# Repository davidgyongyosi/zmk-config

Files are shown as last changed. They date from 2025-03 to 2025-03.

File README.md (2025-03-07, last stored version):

<picture align="center">
  <source media="(prefers-color-scheme: dark)" srcset="/docs/images/TOTEM_logo_dark.svg">
  <source media="(prefers-color-scheme: light)" srcset="/docs/images/TOTEM_logo_bright.svg">
  TOTEM logo
</picture>

<h1 align="center">T O T E M</h1>

TOTEM is a 38 key column-staggered choc split keyboard. It is meant to be used with a [Seeed Studio XIAO nRF52840 BLE](https://www.seeedstudio.com/Seeed-XIAO-BLE-nRF52840-p-5201.html) or [XIAO RP2040](https://www.seeedstudio.com/XIAO-RP2040-v1-0-p-5026.html).
It was created for the SEEED XIAO keyboard contest.\
[Here](https://www.hackster.io/geist/totem-a-tiny-splitkeyboard-with-splay-cb2e43) you can read about the process of making it.

***

## LAYOUT

TOTEM layout

***

## PCB

[Here](/PCB/) you can find the KiCad files and Gerbers for the TOTEM.

***

## CASE

You can use the TOTEM without a case, but [here](/case/) you can find one I made for it.

***

## BUILD GUIDE

The build guide for the TOTEM can be found [here](/docs/buildguide.md).

***

## FIRMWARE

[QMK (VIAL) precompiled](/firmware/QMK/) or [QMK (VIAL) source](/firmware/QMK/VIAL_source/) for the TOTEM (wired using the XIAO RP2040)\
[ZMK precompiled](/firmware/ZMK/) or [ZMK source (outdated)](https://github.com/GEIGEIGEIST/zmk-config-totem) for the TOTEM (wireless using the XIAO BLE)

***

## BUY

You can buy TOTEM kits and finished builds on [keeb.supply](https://keeb.supply/products/geist-totem) (worldwide shipping)

***

## PHOTOS

This is the TOTEM in a black resin case

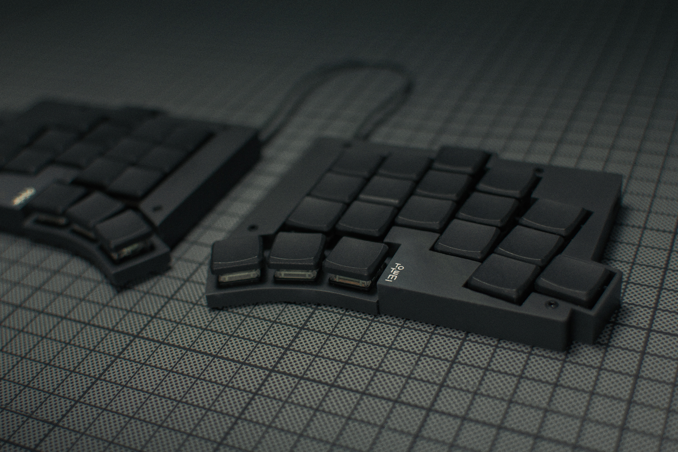
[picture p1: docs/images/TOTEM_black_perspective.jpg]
TOTEM black resin
\
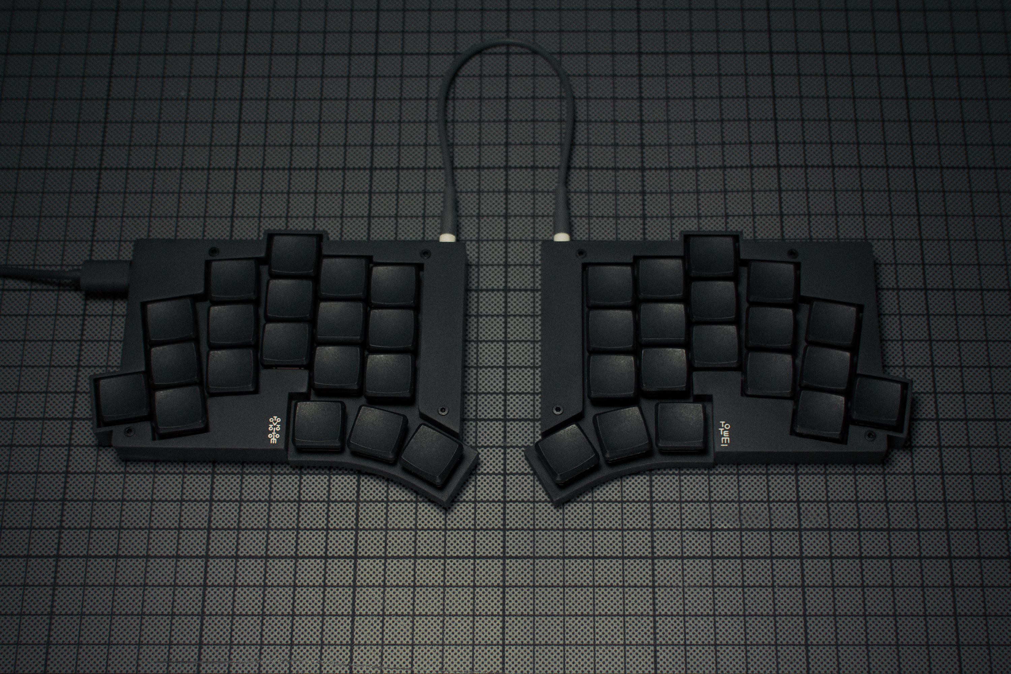
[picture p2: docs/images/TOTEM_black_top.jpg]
TOTEM black resin
\
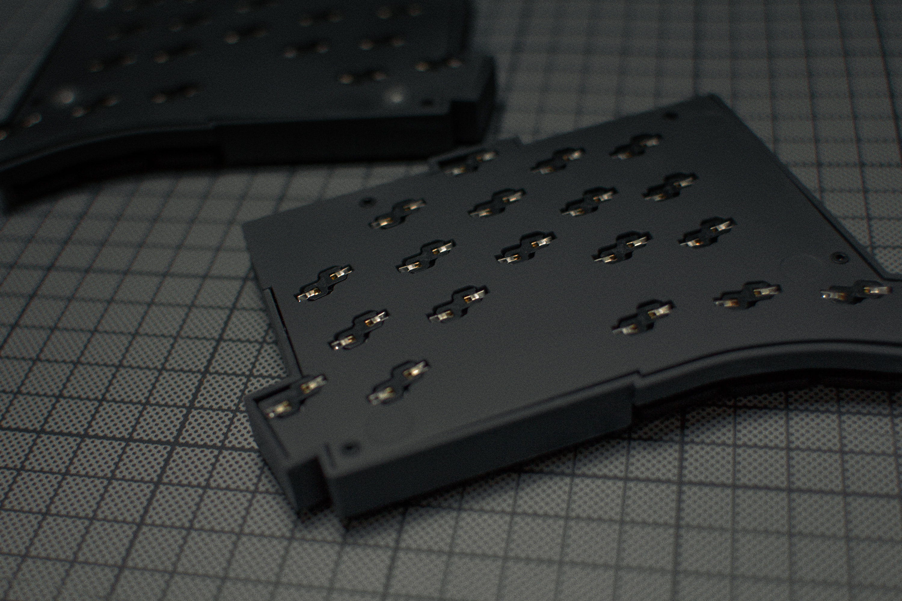
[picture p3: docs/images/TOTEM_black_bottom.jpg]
TOTEM black resin


This is the TOTEM with a black resin tenting bottom plate

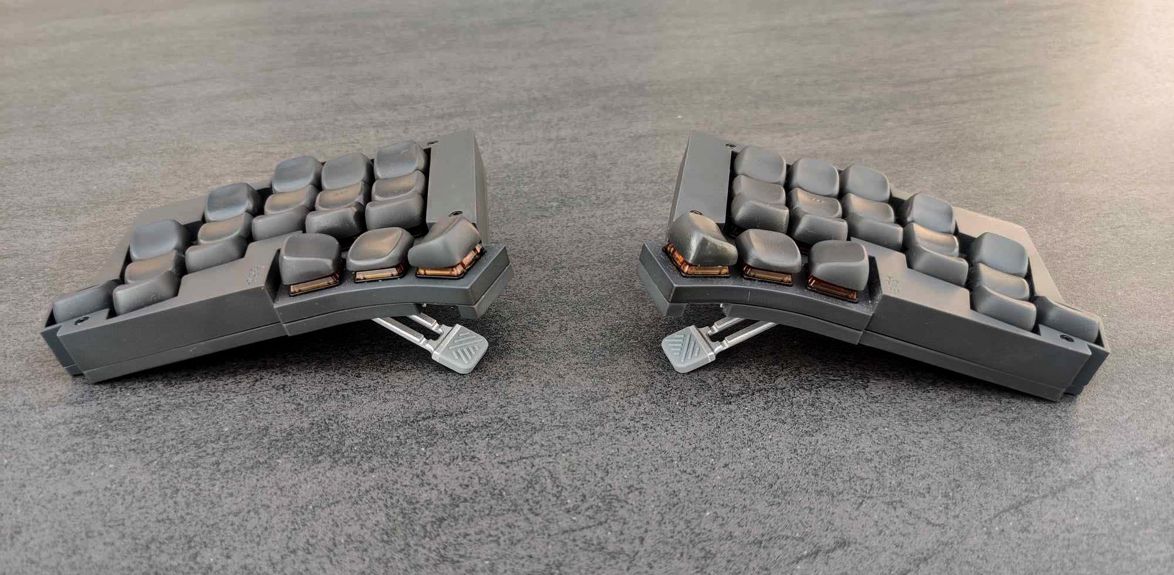
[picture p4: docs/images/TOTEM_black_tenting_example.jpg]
TOTEM black resin tenting
\
[Video by *Wolfgang's Channel* showing the tenting system in action](https://youtu.be/rvM2BthjEI4?si=mTJVdPeZstshnDyo)

***

## CREDITS

### INSPIRATION

I've added the additional pinky key to make the TOTEM compatible with the layout boards like the [Balbuzard](https://github.com/brow/balbuzard) by [Tom Brow](https://github.com/brow) and the [Osprette](https://github.com/smores56/osprette) by [Sam Mohr](https://github.com/smores56) use, where you put the keybinding of the top left and right keys on an outer pinky key.

### HELP FIXING THINGS

People who helped me create this board and fix stuff

#### PCB
- [Marco "Bob"](https://github.com/GroooveBob)

#### CASE
- [Freya](https://github.com/freya-irl)
- [Bubbleology](https://github.com/bubbleology)

#### FIRMWARE
- [Cem Aksoylar](https://github.com/caksoylar)
- [Grinnie](https://github.com/regicidalplutophage)
- [Alaa Saad Mansour](https://github.com/AlaaSaadAbdo)
- [pekudzu](https://github.com/pekudzu)

If you build a TOTEM I would be pretty happy to see some pictures. And if you want to leave me a tip you can do this [here](https://ko-fi.com/geigeigeist) (but please don't feel pressured)

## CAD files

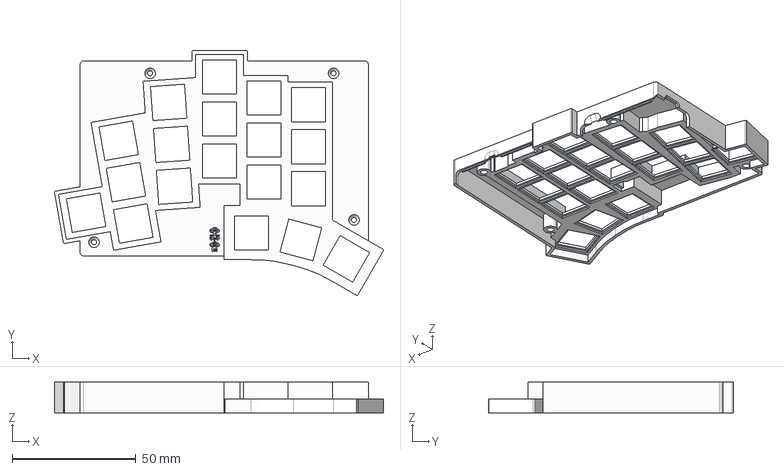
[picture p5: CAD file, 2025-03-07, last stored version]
case/BLE/STEP/TOTEM_case_ble_top_L_V.08.step
133.1 x 99.0 x 12.5 mm

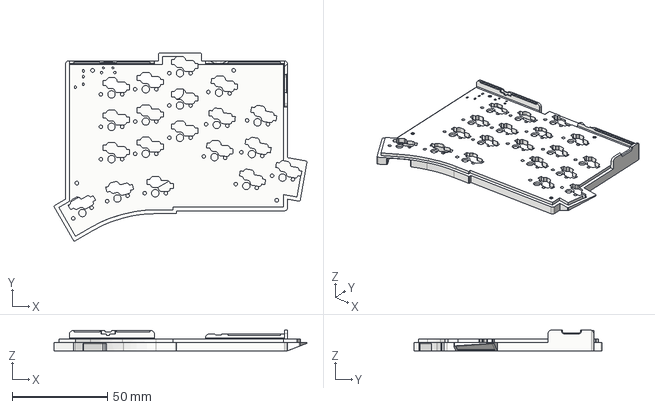
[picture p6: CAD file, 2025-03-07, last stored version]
case/tenting/BLE/step/TOTEMcase_v08_6mm_BLE_Tenting_Bottom_R.step
133.1 x 99.0 x 10.9 mm

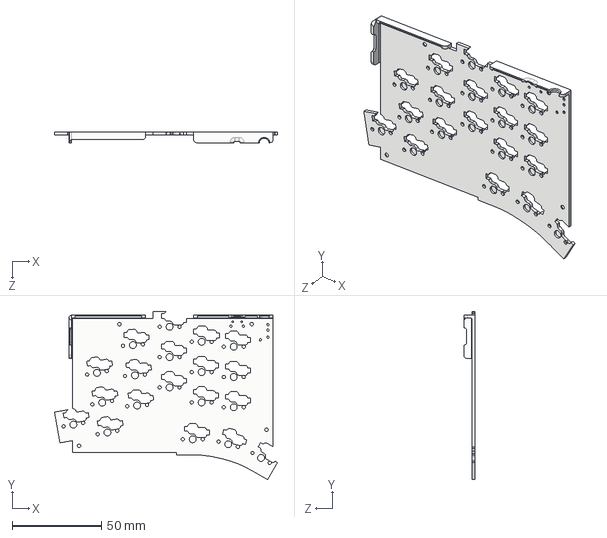
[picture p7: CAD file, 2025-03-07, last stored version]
case/USB/STEP/TOTEM_case_usb_bottom_L_V.08.step
125.1 x 94.5 x 6.40 mm

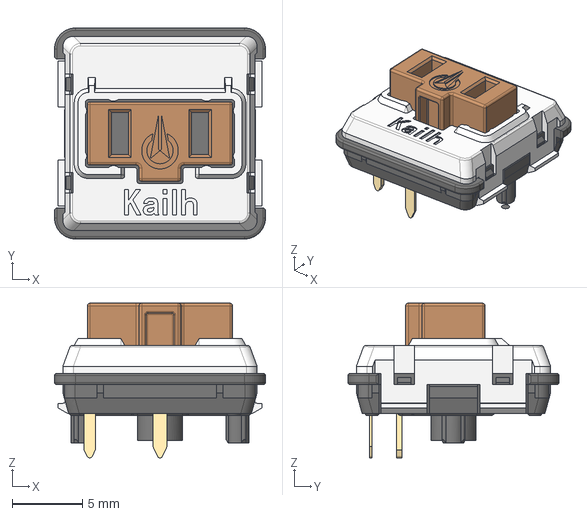
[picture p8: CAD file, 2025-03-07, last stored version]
PCB/totem_0-3/TOTEM3D/Kailh_switch_PG1350_optional.step
15.0 x 15.0 x 11.0 mm

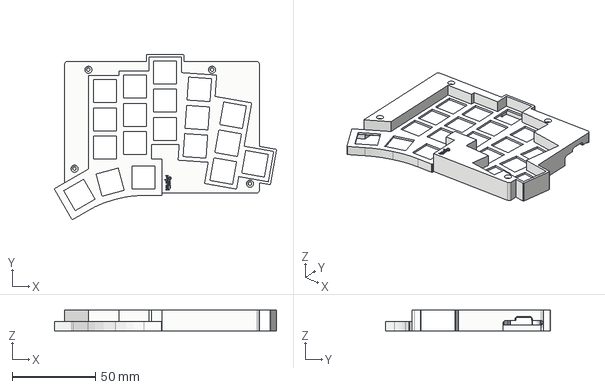
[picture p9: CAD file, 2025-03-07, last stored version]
case/USB/STEP/TOTEM_case_usb_top_R_V.08.step
133.1 x 99.0 x 12.5 mm

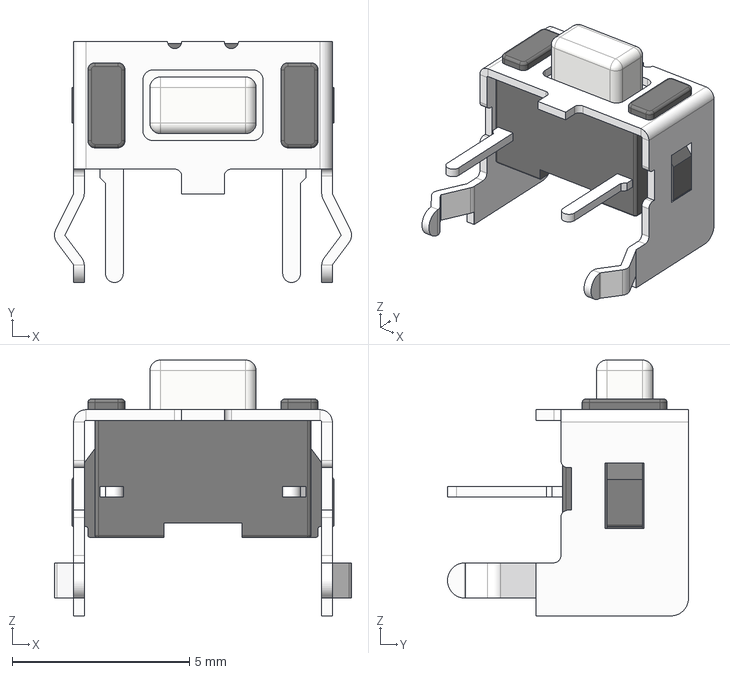
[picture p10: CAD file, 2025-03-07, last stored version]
PCB/totem_0-3/TOTEM3D/SW_SKHLLC.step
8.38 x 6.80 x 7.22 mm

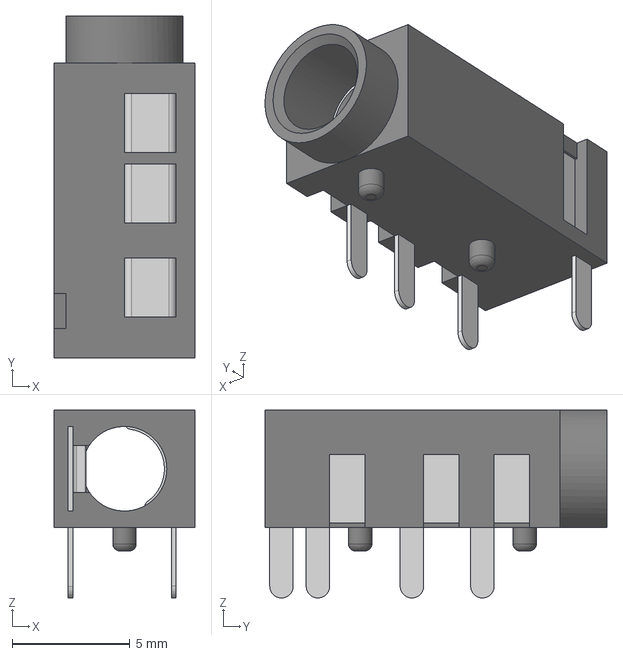
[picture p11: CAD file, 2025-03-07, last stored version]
PCB/totem_0-3/TOTEM3D/PJ320A.STEP
6.00 x 14.6 x 8.00 mm

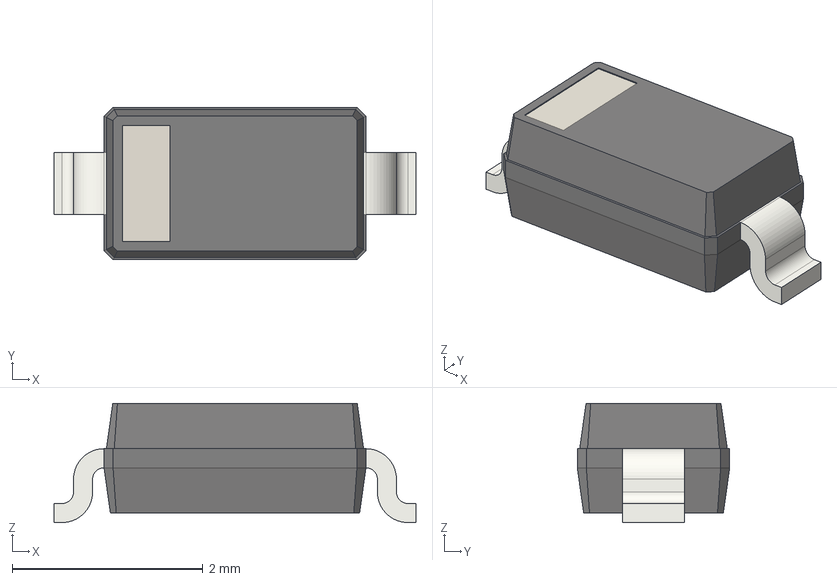
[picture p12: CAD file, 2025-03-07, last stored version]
PCB/totem_0-3/TOTEM3D/D_SOD-123.step
3.80 x 1.60 x 1.25 mm

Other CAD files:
case/tenting/TRX/STEP/TOTEMcase_v08_6mm_TRX_Tenting_Bottom_R.step
case/tenting/USB/STEP/TOTEMcase_v08_6mm_USB_Tenting_Bottom_L.step
case/BLE/STEP/TOTEM_case_ble_bottom_R_V.08.step
case/tenting/BLE/step/TOTEMcase_v08_6mm_BLE_Tenting_Bottom_L.step
case/tenting/TRX/STEP/TOTEMcase_v08_6mm_TRX_Tenting_Bottom_L.step
case/tenting/USB/STEP/TOTEMcase_v08_6mm_USB_Tenting_Bottom_R.step
case/BLE/STEP/TOTEM_case_ble_bottom_L_V.08.step
case/USB/STEP/TOTEM_case_usb_top_L_V.08.step
case/BLE/STEP/TOTEM_case_ble_top_R_V.08.step
case/USB/STEP/TOTEM_case_usb_bottom_R_V.08.step
PCB/totem_0-3/TOTEM3D/Kailh_socket_PG1350_optional.STEP
PCB/totem_0-3/TOTEM3D/MSK12C02.STEP
PCB/totem_0-3/TOTEM3D/xiao-ble-tht.step
case/BLE/STL/TOTEM_case_ble_bottom_L_V.08.STL
case/BLE/STL/TOTEM_case_ble_bottom_R_V.08.STL
case/BLE/STL/TOTEM_case_ble_top_L_V.08.STL
case/BLE/STL/TOTEM_case_ble_top_R_V.08.STL
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

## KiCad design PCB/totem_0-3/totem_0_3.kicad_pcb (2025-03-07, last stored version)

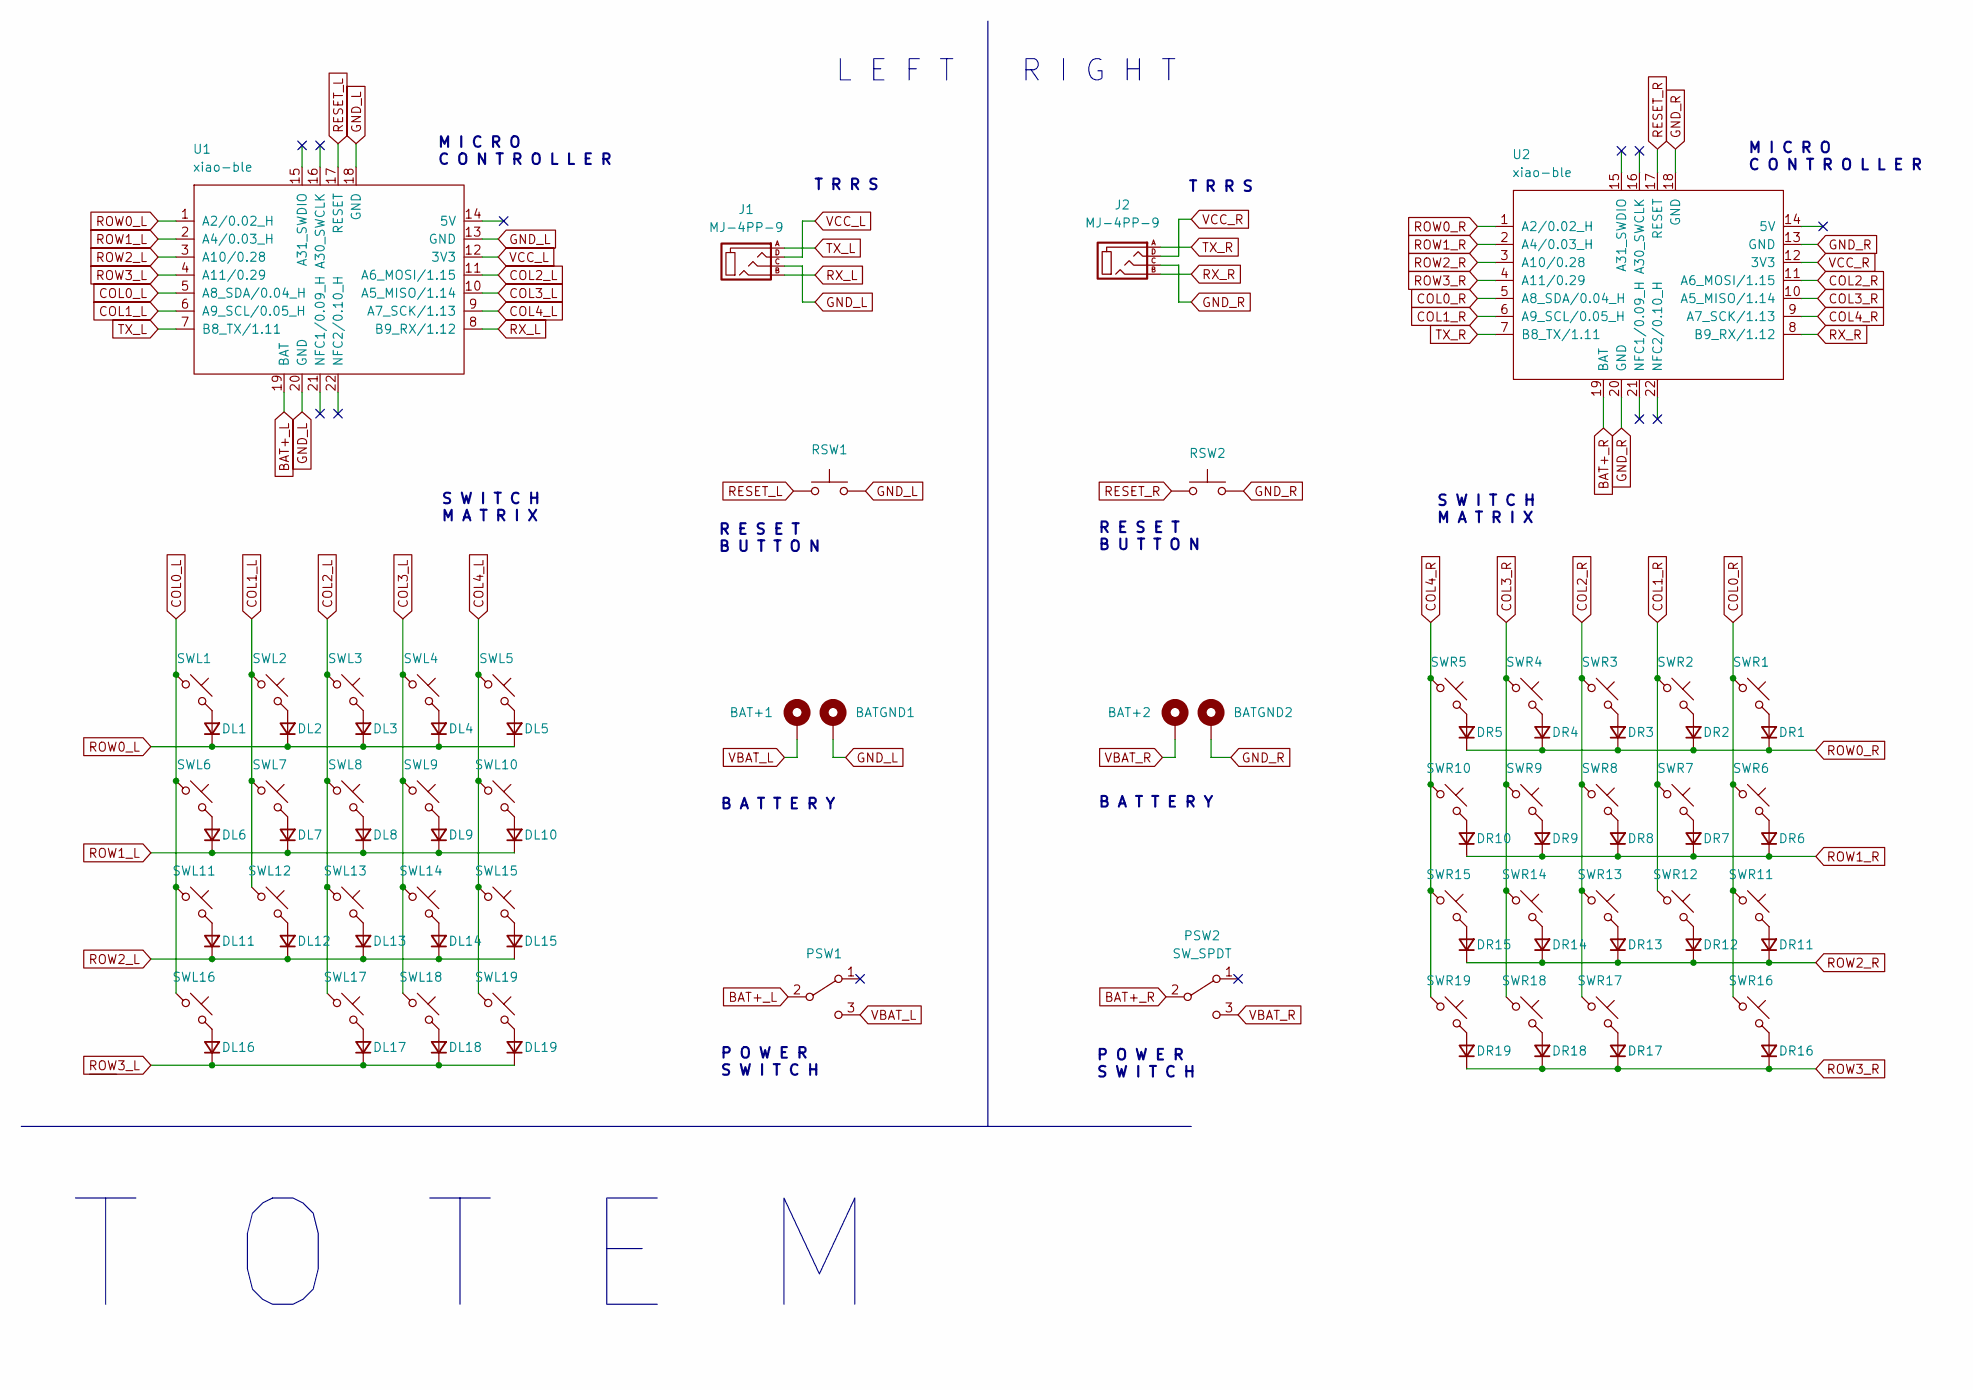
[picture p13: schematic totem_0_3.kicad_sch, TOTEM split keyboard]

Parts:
BAT+1, BAT+2: +; BatteryPad
BATGND1, BATGND2: -; BatteryPad
DL1, DL2, DL3, DL4, DL5, DL6, DL7, DL8, DL9, DL10, DL11, DL12, DL13, DL14, DL15, DL16, DL17, DL18, DL19: D_Small; Diode_SOD123
DR1, DR2, DR3, DR4, DR5, DR6, DR7, DR8, DR9, DR10, DR11, DR12, DR13, DR14, DR15, DR16, DR17, DR18, DR19: D_Small; Diode_SOD123
J1, J2: MJ-4PP-9; MJ-4PP-9_1side
PSW1, PSW2: SW_SPDT; MSK12C02
RSW1, RSW2: SW_Push; SKHLLCA010
SWL1, SWL2, SWL3, SWL4, SWL5, SWL6, SWL7, SWL8, SWL9, SWL10, SWL11, SWL12, SWL13, SWL14, SWL15, SWL16, SWL17, SWL18, SWL19: SW_Push_45deg; Kailh_socket_PG1350_optional
SWR1, SWR2, SWR3, SWR4, SWR5, SWR6, SWR7, SWR8, SWR9, SWR10, SWR11, SWR12, SWR13, SWR14, SWR15, SWR16, SWR17, SWR18, SWR19: SW_Push_45deg; Kailh_socket_PG1350_optional
U1, U2: xiao-ble; xiao-ble-smd-cutout

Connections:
BAT+_L: PSW1.2 (B), U1.19 (BAT); also elsewhere on the board
BAT+_R: PSW2.2 (B), U2.19 (BAT); also elsewhere on the board
COL0_L: SWL1.1, SWL6.1, SWL11.1, SWL16.1, U1.5 (A8_SDA/0.04_H)
COL0_R: SWR1.1, SWR6.1, SWR11.1, SWR16.1, U2.5 (A8_SDA/0.04_H)
COL1_L: SWL2.1, SWL7.1, SWL12.1, U1.6 (A9_SCL/0.05_H)
COL1_R: SWR2.1, SWR7.1, SWR12.1, U2.6 (A9_SCL/0.05_H)
COL2_L: SWL3.1, SWL8.1, SWL13.1, SWL17.1, U1.11 (A6_MOSI/1.15)
COL2_R: SWR3.1, SWR8.1, SWR13.1, SWR17.1, U2.11 (A6_MOSI/1.15)
COL3_L: SWL4.1, SWL9.1, SWL14.1, SWL18.1, U1.10 (A5_MISO/1.14)
COL3_R: SWR4.1, SWR9.1, SWR14.1, SWR18.1, U2.10 (A5_MISO/1.14)
COL4_L: SWL5.1, SWL10.1, SWL15.1, SWL19.1, U1.9 (A7_SCK/1.13)
COL4_R: SWR5.1, SWR10.1, SWR15.1, SWR19.1, U2.9 (A7_SCK/1.13)
GND_L: BATGND1.1, J1.C, RSW1.2, U1.13 (GND), U1.18 (GND), U1.20 (GND)
GND_R: BATGND2.1, J2.C, RSW2.2, U2.13 (GND), U2.18 (GND), U2.20 (GND); also elsewhere on the board
unnamed: DL1.2 (A), SWL1.2
unnamed: DL2.2 (A), SWL2.2
unnamed: DL3.2 (A), SWL3.2
unnamed: DL4.2 (A), SWL4.2
unnamed: DL5.2 (A), SWL5.2
unnamed: DL6.2 (A), SWL6.2
unnamed: DL7.2 (A), SWL7.2
unnamed: DL8.2 (A), SWL8.2
unnamed: DL9.2 (A), SWL9.2
unnamed: DL10.2 (A), SWL10.2
unnamed: DL11.2 (A), SWL11.2
unnamed: DL12.2 (A), SWL12.2
unnamed: DL13.2 (A), SWL13.2
unnamed: DL14.2 (A), SWL14.2
unnamed: DL15.2 (A), SWL15.2
unnamed: DL16.2 (A), SWL16.2
unnamed: DL17.2 (A), SWL17.2
unnamed: DL18.2 (A), SWL18.2
unnamed: DL19.2 (A), SWL19.2
unnamed: DR1.2 (A), SWR1.2
unnamed: DR2.2 (A), SWR2.2
unnamed: DR3.2 (A), SWR3.2
unnamed: DR4.2 (A), SWR4.2
unnamed: DR5.2 (A), SWR5.2
unnamed: DR6.2 (A), SWR6.2
unnamed: DR7.2 (A), SWR7.2
unnamed: DR8.2 (A), SWR8.2
unnamed: DR9.2 (A), SWR9.2
unnamed: DR10.2 (A), SWR10.2
unnamed: DR11.2 (A), SWR11.2
unnamed: DR12.2 (A), SWR12.2
unnamed: DR13.2 (A), SWR13.2
unnamed: DR14.2 (A), SWR14.2
unnamed: DR15.2 (A), SWR15.2
unnamed: DR16.2 (A), SWR16.2
unnamed: DR17.2 (A), SWR17.2
unnamed: DR18.2 (A), SWR18.2
unnamed: DR19.2 (A), SWR19.2
RESET_L: RSW1.1, U1.17 (RESET)
RESET_R: RSW2.1, U2.17 (RESET); also elsewhere on the board
ROW0_L: DL1.1 (K), DL2.1 (K), DL3.1 (K), DL4.1 (K), DL5.1 (K), U1.1 (A2/0.02_H)
ROW0_R: DR1.1 (K), DR2.1 (K), DR3.1 (K), DR4.1 (K), DR5.1 (K), U2.1 (A2/0.02_H)
ROW1_L: DL6.1 (K), DL7.1 (K), DL8.1 (K), DL9.1 (K), DL10.1 (K), U1.2 (A4/0.03_H)
ROW1_R: DR6.1 (K), DR7.1 (K), DR8.1 (K), DR9.1 (K), DR10.1 (K), U2.2 (A4/0.03_H)
ROW2_L: DL11.1 (K), DL12.1 (K), DL13.1 (K), DL14.1 (K), DL15.1 (K), U1.3 (A10/0.28)
ROW2_R: DR11.1 (K), DR12.1 (K), DR13.1 (K), DR14.1 (K), DR15.1 (K), U2.3 (A10/0.28)
ROW3_L: DL16.1 (K), DL17.1 (K), DL18.1 (K), DL19.1 (K), U1.4 (A11/0.29)
ROW3_R: DR16.1 (K), DR17.1 (K), DR18.1 (K), DR19.1 (K), U2.4 (A11/0.29)
RX_L: J1.B, U1.8 (B9_RX/1.12)
RX_R: J2.B, U2.8 (B9_RX/1.12)
TX_L: J1.A, U1.7 (B8_TX/1.11)
TX_R: J2.A, U2.7 (B8_TX/1.11)
VBAT_L: BAT+1.1, PSW1.3 (C); also elsewhere on the board
VBAT_R: BAT+2.1, PSW2.3 (C); also elsewhere on the board
VCC_L: J1.D, U1.12 (3V3)
VCC_R: J2.D, U2.12 (3V3)

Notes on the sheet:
M I C R O C O N T R O L L E R
T R R S
R E S E T B U T T O N
S W I T C H M A T R I X
P O W E R S W I T C H
T O T E M
B A T T E R Y
R I G H T
L E F T

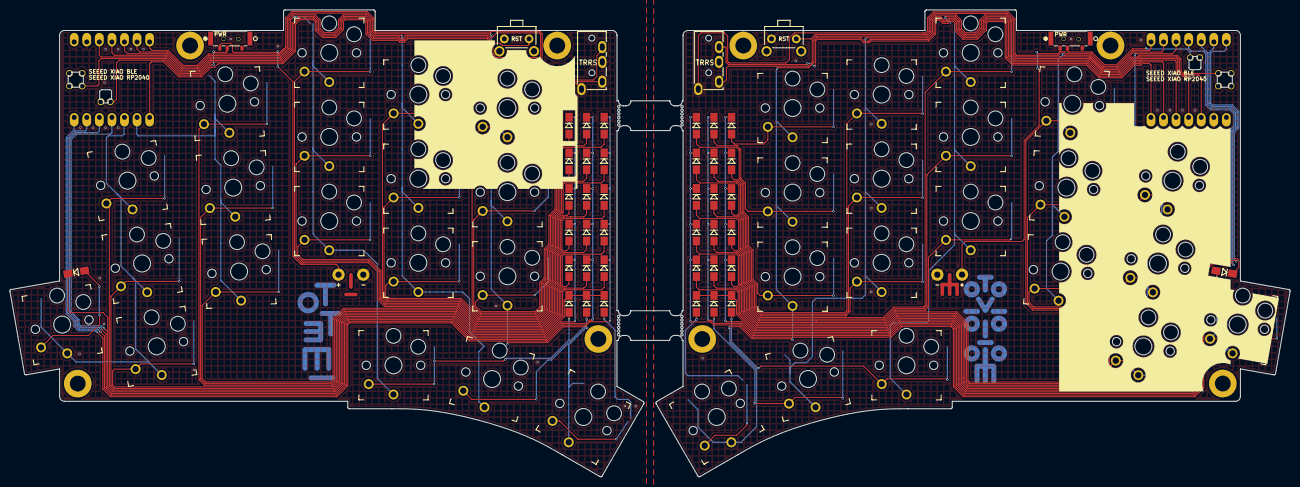
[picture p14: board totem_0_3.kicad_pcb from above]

Board: 2 copper layers, 258.7 x 94.4 mm, 88 parts (0 on the bottom side), 70 nets.

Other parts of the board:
PWR: SW_SPDT; MSK12C02
PWR#2: SW_SPDT; MSK12C02
RST: SW_Push; SKHLLCA010

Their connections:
BAT+_L: PWR.2 (B); also elsewhere on the board
BAT+_R: PWR#2.2 (B); also elsewhere on the board
GND_R: RST.2; also elsewhere on the board
RESET_R: RST.1; also elsewhere on the board
VBAT_L: PWR.3 (C); also elsewhere on the board
VBAT_R: PWR#2.3 (C); also elsewhere on the board

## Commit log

2025-03-07 totem "fork"
    [D_SOD-123.step, Kailh_socket_PG1350_optional.STEP, Kailh_switch_PG1350_optional.step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]
2025-03-07 totem prospector config
    [D_SOD-123.step, Kailh_socket_PG1350_optional.STEP, Kailh_switch_PG1350_optional.step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]
2025-10-19 y-z switch
2026-08-21 Pin ZMK to v0.3 and Prospector module to fix build
    ZMK main moved to Zephyr 4.1 with breaking changes, but
    prospector-zmk-module targets ZMK v0.3 (Zephyr 3.5), causing an
    undefined reference to as_zmk_modifiers_state_changed at link time.
    Pin zmk to v0.3 and the module to a fixed commit for stability.
2026-08-21 Pin build workflow to v0.3 to match pinned ZMK
    The firmware compiles, but build-user-config.yml@main runs new
    Zephyr-4.1 post-build checks (CONFIG_ZMK_BOARD_COMPAT and board
    qualifier parsing) that fail on v0.3 boards. Pin the reusable
    workflow to @v0.3 so it matches the pinned ZMK revision.
